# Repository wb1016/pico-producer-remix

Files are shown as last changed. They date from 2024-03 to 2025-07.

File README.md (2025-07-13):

# ARCHIVED
### will be on work for new fork
# Pico Producer remix by Blue_ON

a shorcut keypad using YD-RP2040/Pi Pico.\
original project by https://github.com/pjgpetecodes/pico-streamdeck

# Parts List
all parts are THT components, making easy to assemble.

| Part | Qty | note |
|---|-----|---|
| PCB | 1 | generate with kicad |
| 3mm THT LED | 12 |  |
| Cherry MX switches | 12 | compatible switches can be used | 
| 1k Ohm THT Resistor | 12 |  |
| YD-RP2040 | 1 | you can use Pi Pico instead |
| 20 pin Header pin | 2 | will come with YD-RP2040 |
| 3D Printed Case | 1 |  |
| 3D printed keycaps | 12 |  |
| 3D printed faceplate | 1 |  |

Notes: 
- you can use Pi Pico instead, but you will need external WS2812B LED.
- print 3D models with 25% infill at least.

# Instructions
- connect YD-RP2040 to computer while pressing onboard BOOT button.
- download circuitpython for YD-RP2040 [link](https://circuitpython.org/board/vcc_gnd_yd_rp2040/)
- install circuitpython to YD-RP2040 by copying uf2 file to newly appeared drive.
- install [neopixel driver](https://github.com/adafruit/Adafruit_CircuitPython_NeoPixel/releases) to 'CIRCUITPY' drive
- install [hid library](https://github.com/adafruit/Adafruit_CircuitPython_HID/releases) to 'CIRCUITPY' drive
- copy code.py to 'CIRCUITPY' drive and disconnect the board from computer.
- solder the R68 jumper on the YD-RP2040. this enables onboard RGB LED.
- solder LEDs to PCB.
- solder resistors to PCB.
- solder pin header to PCB.
- solder key switches to PCB.
- solder YD-RP2040 to PCB.
- trim the header pins.
- assemble all together.

## CircuitPython HID

You can find some more info about the CircuitPython KeyMappings here;

https://circuitpython.readthedocs.io/projects/hid/en/latest/_modules/adafruit_hid/keycode.html

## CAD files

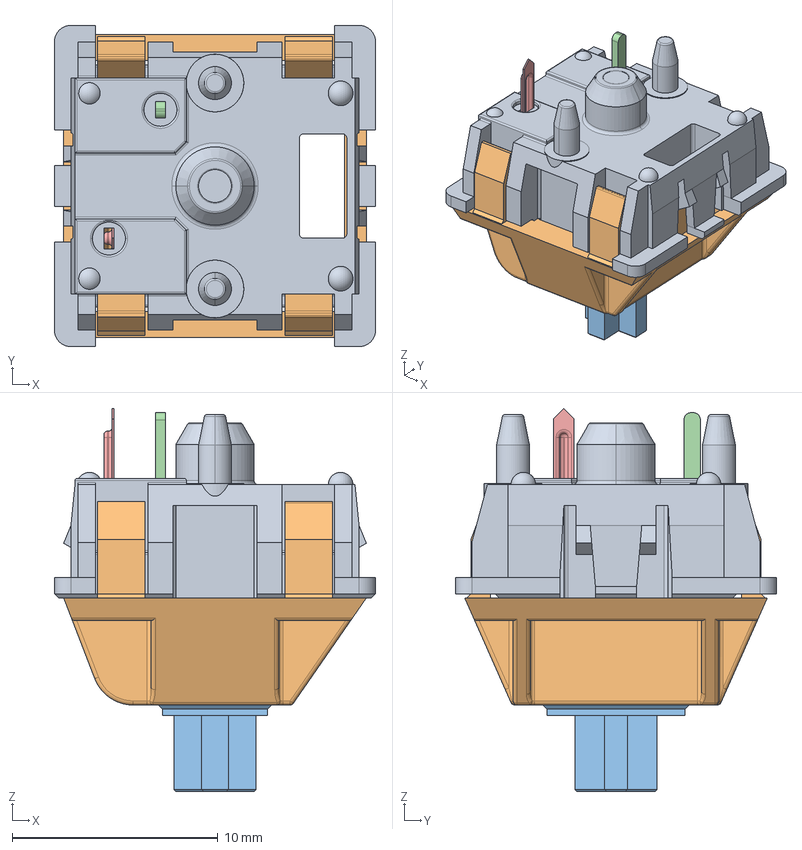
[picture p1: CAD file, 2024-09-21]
asm_mx_asm_PCB.stp
15.6 x 15.6 x 18.6 mm
MX_DOWN
MX_UP
UP_MX
MX_PIN
MX_SPRING
MX_CLICK

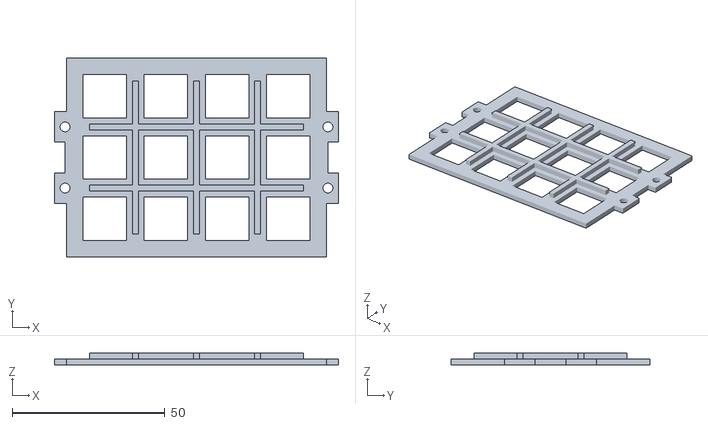
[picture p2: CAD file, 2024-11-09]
3dfiles/Faceplate.stl
92.9 x 65.0 x 4.00

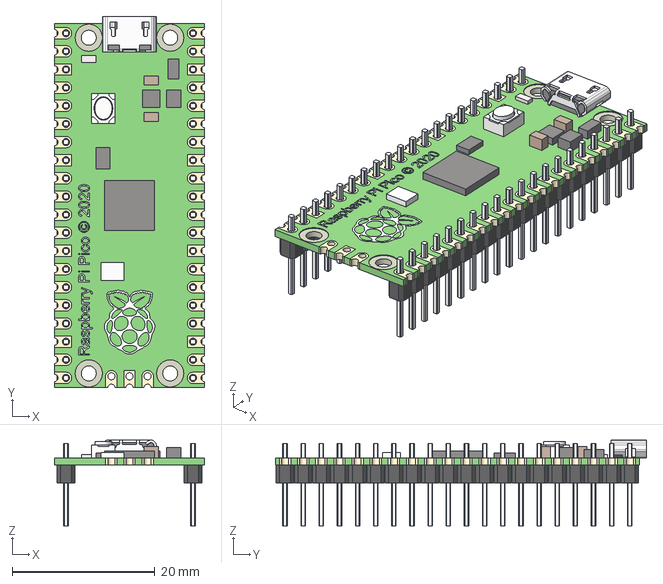
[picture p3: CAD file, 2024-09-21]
raspberry pi pico with contacts.step
21.0 x 52.0 x 12.0 mm
ножка x 20
ножка v3(Mirror) x 20

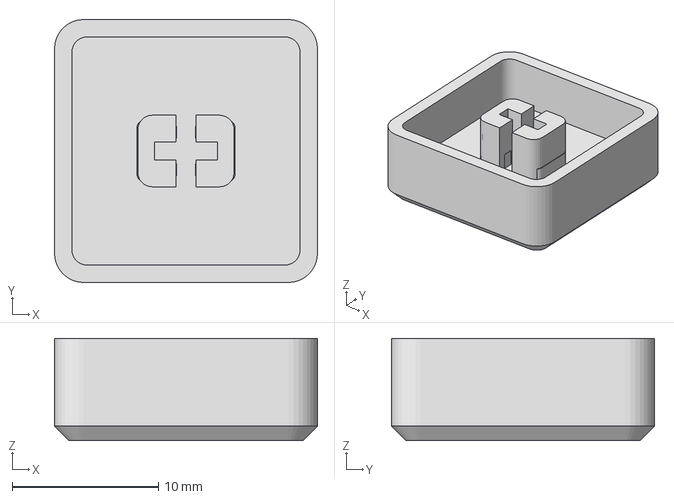
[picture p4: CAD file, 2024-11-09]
3dfiles/keycap.3mf
18.0 x 18.0 x 7.00 mm

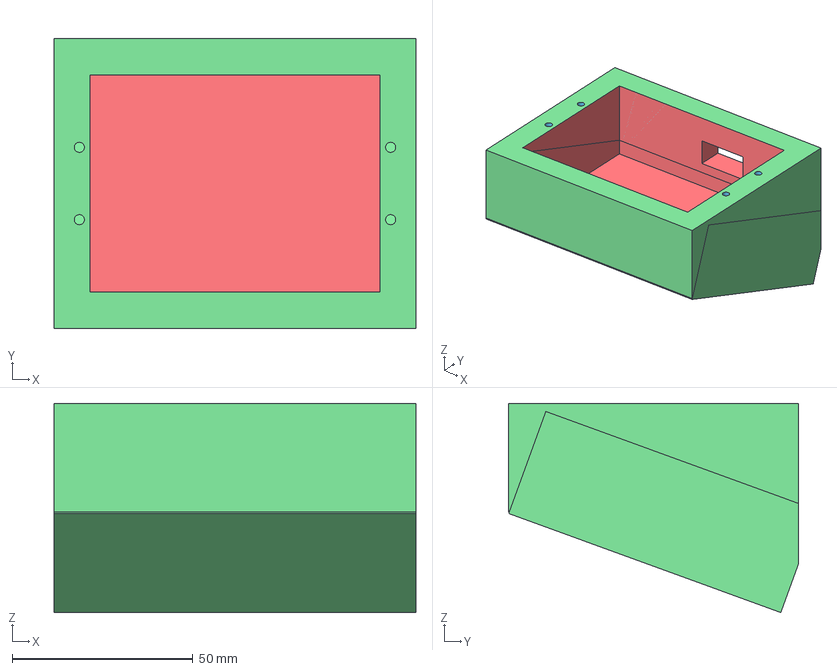
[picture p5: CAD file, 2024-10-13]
3dfiles/Case.3mf
100.0 x 80.0 x 57.8 mm

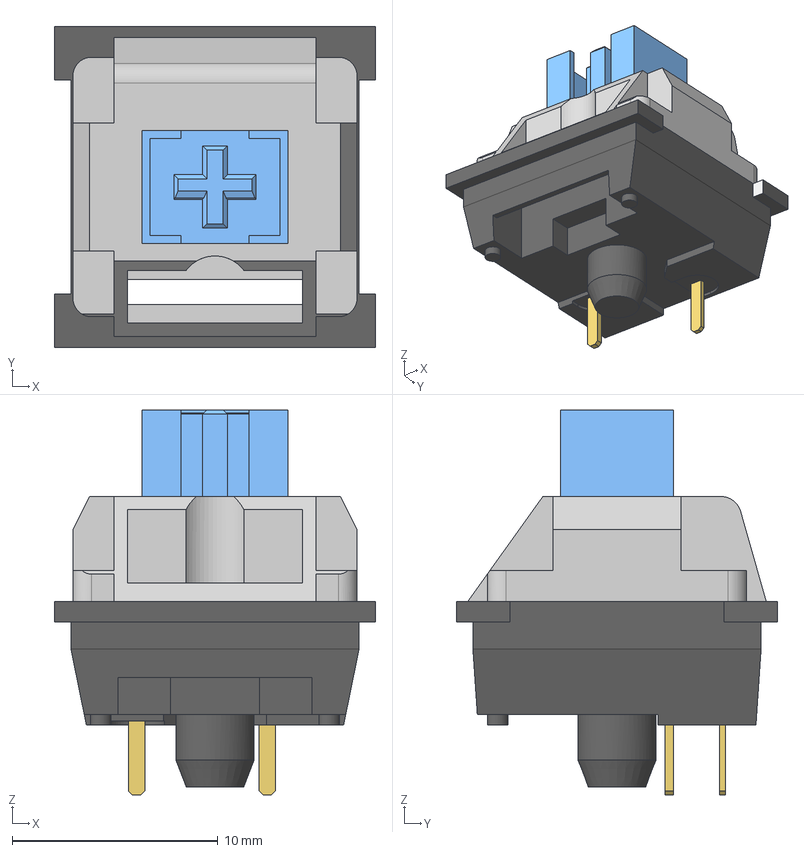
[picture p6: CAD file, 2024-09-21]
REDragon-MX-ZT02.stp
15.6 x 15.6 x 18.7 mm
Button
Pins

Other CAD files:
3dfiles/Case.stl

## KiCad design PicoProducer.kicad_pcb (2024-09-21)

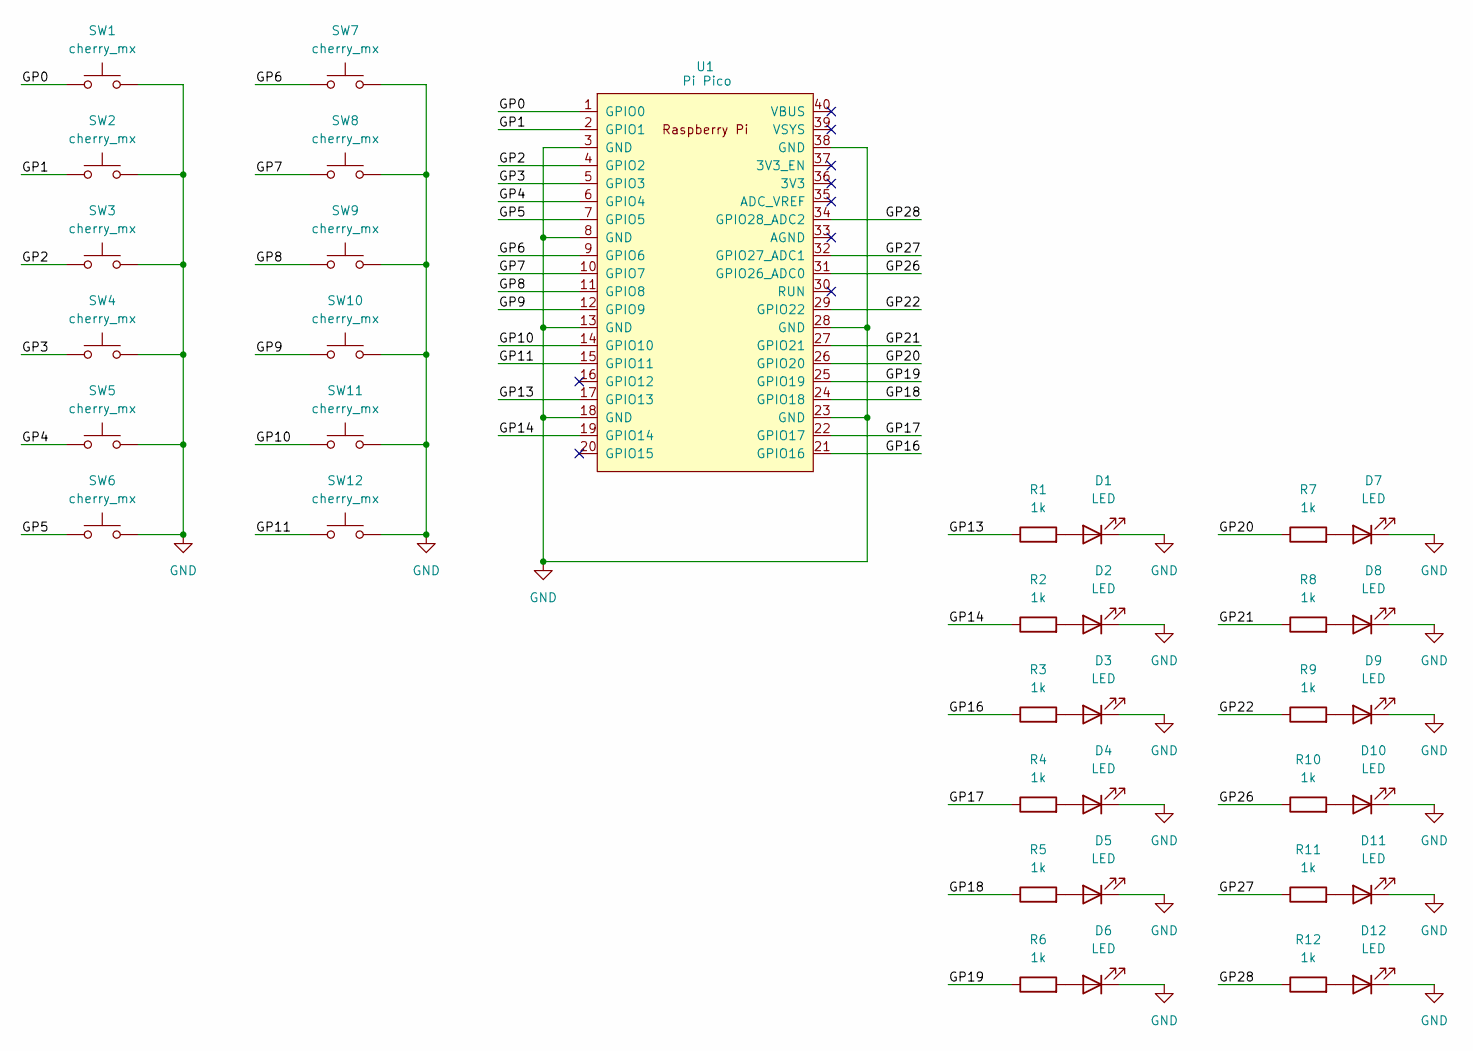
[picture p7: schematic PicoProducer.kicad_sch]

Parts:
D1, D2, D3, D4, D5, D6, D7, D8, D9, D10, D11, D12: LED; LED_0805_2012Metric_Pad1.15x1.40mm_HandSolder
R1, R2, R3, R4, R5, R6, R7, R8, R9, R10, R11, R12: 1k; R_0805_2012Metric_Pad1.20x1.40mm_HandSolder
SW1, SW2, SW3, SW4, SW5, SW6, SW7, SW8, SW9, SW10, SW11, SW12: cherry_mx; SW_Cherry_MX_1.00u_PCB
U1: Pi Pico; YD-RP2040

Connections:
/GP0: SW1.1, U1.1 (GPIO0)
/GP1: SW2.1, U1.2 (GPIO1)
/GP2: SW3.1, U1.4 (GPIO2)
/GP3: SW4.1, U1.5 (GPIO3)
/GP4: SW5.1, U1.6 (GPIO4)
/GP5: SW6.1, U1.7 (GPIO5)
/GP6: SW7.1, U1.9 (GPIO6)
/GP7: SW8.1, U1.10 (GPIO7)
/GP8: SW9.1, U1.11 (GPIO8)
/GP9: SW10.1, U1.12 (GPIO9)
/GP10: SW11.1, U1.14 (GPIO10)
/GP11: SW12.1, U1.15 (GPIO11)
/GP13: R1.1, U1.17 (GPIO13)
/GP14: R2.1, U1.19 (GPIO14)
/GP16: R3.1, U1.21 (GPIO16)
/GP17: R4.1, U1.22 (GPIO17)
/GP18: R5.1, U1.24 (GPIO18)
/GP19: R6.1, U1.25 (GPIO19)
/GP20: R7.1, U1.26 (GPIO20)
/GP21: R8.1, U1.27 (GPIO21)
/GP22: R9.1, U1.29 (GPIO22)
/GP26: R10.1, U1.31 (GPIO26_ADC0)
/GP27: R11.1, U1.32 (GPIO27_ADC1)
/GP28: R12.1, U1.34 (GPIO28_ADC2)
GND: D1.1 (K), D2.1 (K), D3.1 (K), D4.1 (K), D5.1 (K), D6.1 (K), D7.1 (K), D8.1 (K), D9.1 (K), D10.1 (K), D11.1 (K), D12.1 (K), SW1.2, SW2.2, SW3.2, SW4.2, SW5.2, SW6.2, SW7.2, SW8.2, SW9.2, SW10.2, SW11.2, SW12.2, U1.3 (GND), U1.8 (GND), U1.13 (GND), U1.18 (GND), U1.23 (GND), U1.28 (GND), U1.38 (GND)
unnamed: D1.2 (A), R1.2
unnamed: D2.2 (A), R2.2
unnamed: D3.2 (A), R3.2
unnamed: D4.2 (A), R4.2
unnamed: D5.2 (A), R5.2
unnamed: D6.2 (A), R6.2
unnamed: D7.2 (A), R7.2
unnamed: D8.2 (A), R8.2
unnamed: D9.2 (A), R9.2
unnamed: D10.2 (A), R10.2
unnamed: D11.2 (A), R11.2
unnamed: D12.2 (A), R12.2

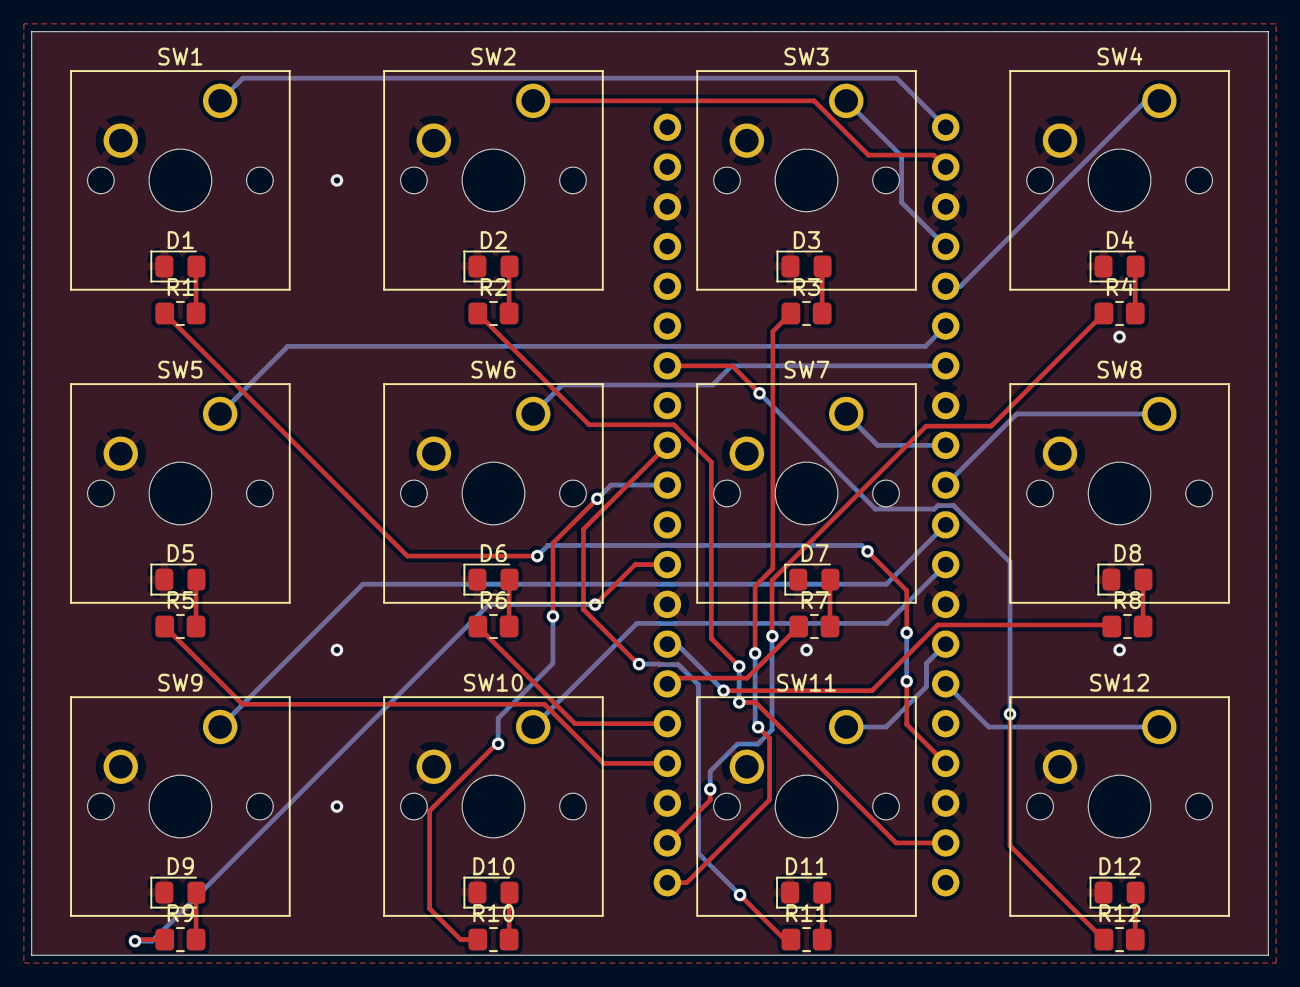
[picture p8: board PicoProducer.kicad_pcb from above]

Board: 2 copper layers, 79.0 x 59.0 mm, 37 parts (1 on the bottom side), 37 nets.

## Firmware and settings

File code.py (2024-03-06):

# Blue_ON Mar 2024
# MIT
#
# Pete Gallagher 11th February 2021
# MIT
#
# 2022 Dan Halbert for Adafruit Industries
# MIT

import time
import digitalio
import board
import keypad
import neopixel
import usb_hid

from adafruit_hid.keyboard import Keyboard
from adafruit_hid.keycode import Keycode

KEY_PINS = (
    board.GP0,
    board.GP1,
    board.GP2,
    board.GP3,
    board.GP4,
    board.GP5,
    board.GP6,
    board.GP7,
    board.GP8,
    board.GP9,
    board.GP10,
    board.GP11,
)

LED_PINS = [
    board.GP13,
    board.GP14,
    board.GP16,
    board.GP17,
    board.GP18,
    board.GP19,
    board.GP20,
    board.GP21,
    board.GP22,
    board.GP26,
    board.GP27,
    board.GP28,
]

KEYCODES = (
    Keycode.F13,
    Keycode.F14,
    Keycode.F15,
    Keycode.F16,
    Keycode.F17,
    Keycode.F18,
    Keycode.F19,
    Keycode.F20,
    Keycode.F21,
    Keycode.F22,
    Keycode.F23,
    Keycode.F24,
)

ON_COLOR = (0, 0, 255)
OFF_COLOR = (0, 128, 0)

led_pin_array = [0,0,0,0,0,0,0,0,0,0,0,0]

for i in range(12):
    led_pin = digitalio.DigitalInOut(LED_PINS[i])
    led_pin.direction = digitalio.Direction.OUTPUT
    led_pin_array[i] = led_pin

keys = keypad.Keys(KEY_PINS, value_when_pressed=False, pull=True)
neopixels = neopixel.NeoPixel(board.GP23, 1, brightness=1)
neopixels.fill(OFF_COLOR)
kbd = Keyboard(usb_hid.devices)


while True:
    event = keys.events.get()
    if event:
        key_number = event.key_number
        # A key transition occurred.
        if event.pressed:
            kbd.press(KEYCODES[key_number])
            neopixels[0] = ON_COLOR
            
            for i in range(12):
                led_pin_array[i].value=False
                
            led_pin_array[key_number].value=True

        if event.released:
            kbd.release(KEYCODES[key_number])
            neopixels[0] = OFF_COLOR
    # debounce for 1ms
    time.sleep(0.001)

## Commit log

2024-03-06 ඞreadmeඞ
2024-03-10 reorder readme, enlarge usb port hole in case stl
    [Case.stl]
2024-03-22 case hight adjustment
    [Case.stl]
2024-03-22 thicken faceplate
    [Faceplate.stl]
2024-03-22 maybe that was too thicc
    [Faceplate.stl]
2024-09-21 resolve drc errors
    [PicoProducer.kicad_pcb]
2024-11-09 3dfiles update
    [Faceplate.step, Faceplate.stl, keycap.3mf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]
2024-11-09 refine 3dfiles
    [Faceplate.stl, keycap.3mf]
